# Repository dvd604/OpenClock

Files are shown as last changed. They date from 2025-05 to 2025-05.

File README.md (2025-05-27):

# OpenClock
Raspberry Pi Pico / ESPHome based central heating controller







# Background
I bought a house that had a "dumb" heating controller - a heating clock that switched zones on and off on a schedule. It had three zones, as my house has a hot water, upstairs and downstairs loop.
I replaced it for a Nest Learning Thermostat 3, and was very unimpressed with it - It only had water and one zone, and the app design was terrible. For me (having an oil fired boilder), I wanted to turn the heating on for an hour in the morning to get the house warm, and give me hot water for a shower, and that's about it. Obviously as the name suggests, the Nest Thermostat wanted to get the house to a temperature and hold it there, which didn't work for me.

To fix this, I designed OpenClock - an ESPHome based heating clock built around readily available parts that would integrate into my already mature smart home system, giving me the ability to make the control of this clock as simple or as complex as I wanted. It was also a learning tool for me, being the second time I've designed circuitry for UK mains (240V) applications.

While I wouldn't recommend anyone build this (as I have limited experience with designing mains application devices), and this repo is more for demonstration purposes, I have been using OpenClock for over a year without issue.

# Features

* Designed to screw to a UK single gang backbox
* 3 Heating zones, can be switched on and off independantly
* Runs ESPHome on a RPi Pico, so firmware can be modified

# Heating systems known to work

Only tested in my house - has an oil fired boiler, which is controlled in two ways:

1. The water "zone" sends mains power directly to the water "zone" valve - this valve opens, and a switch inside the valve then powers the boiler.
2. The room "zones" send mains power to a room thermostat - this thermostat has the final say over whether the room "zone" valve opens, which when opened, powers the boiler as above.
 
# The benefit of hindsight

While OpenClock has worked well for over a year, having spent some time with it, I now know how I would do it different - and probably will. If I was doing this centralised control method again, I would buy a Shelly relay - these guys have far more experience than me with designing safe electronics, and their hardware is small enough to fit in a UK backbox. One of their relays probably costs less than the price of the PCBs alone.

However, I've come to strongly dislike my room thermostats - they're loud when switching, difficult to use, and are very feature-light. By this I mean, they turn on and off with temperature in a room.
To fix this, I would hardwire the mains wires where OpenClock is at the moment, so the room thermostats are receiving power all the time, and install something like the Sonoff NSPanel. This would add so many more options into the rooms where the thermostats are mounted.

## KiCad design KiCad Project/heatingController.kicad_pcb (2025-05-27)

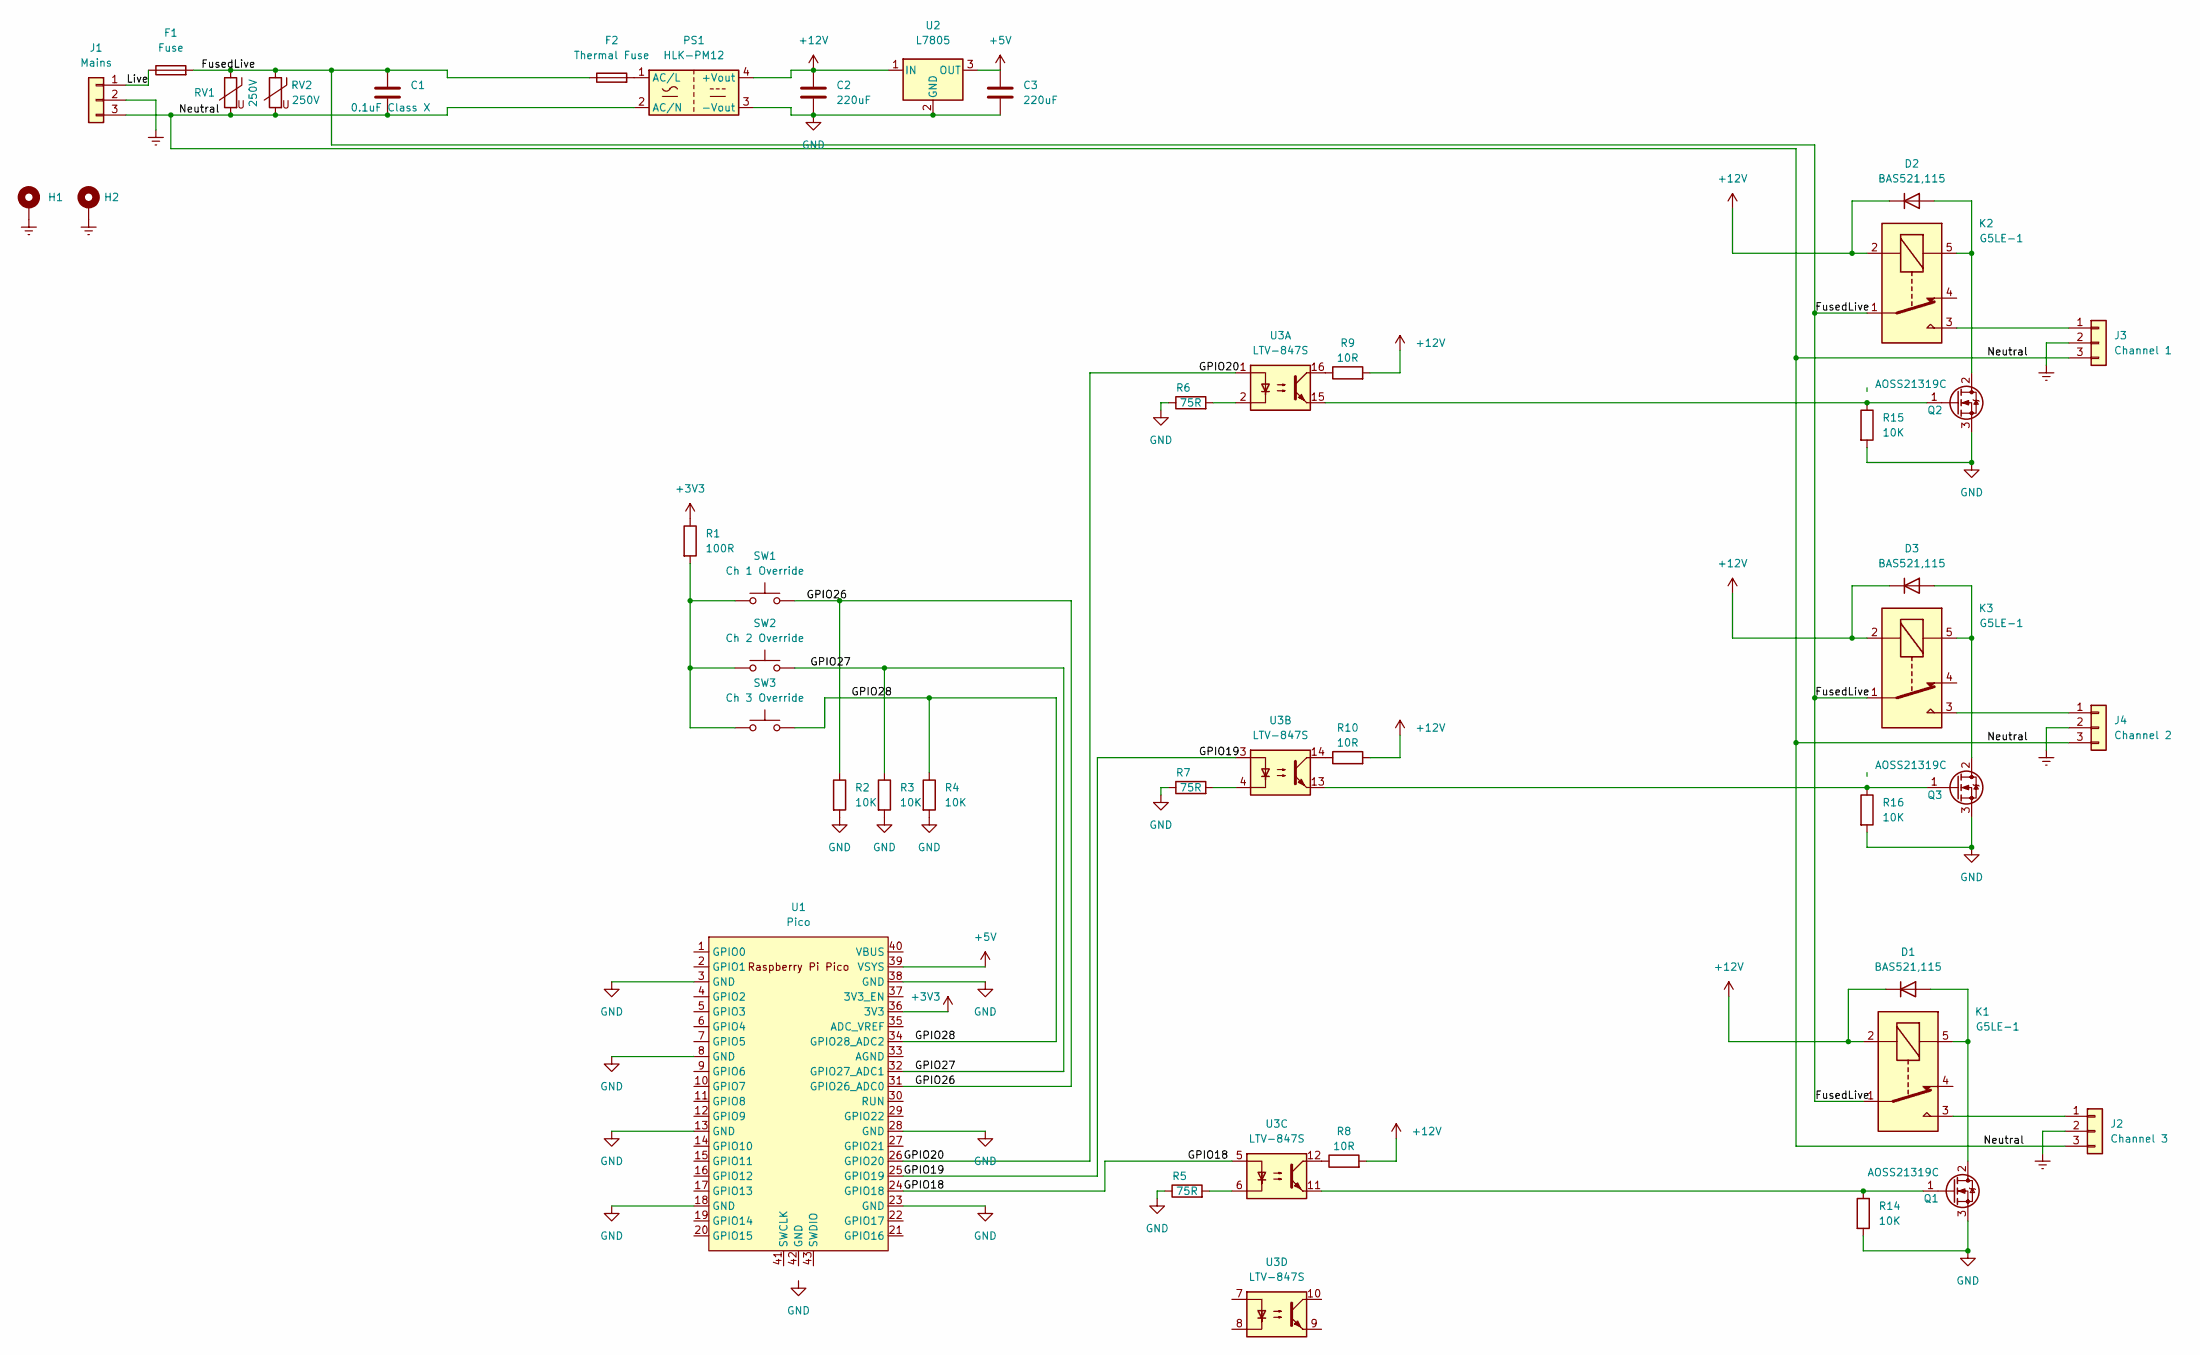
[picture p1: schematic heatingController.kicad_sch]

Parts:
C1: 0.1uF Class X; C_Rect_L18.0mm_W8.0mm_P15.00mm_FKS3_FKP3
C2, C3: 220uF; R_0603_1608Metric_Pad0.98x0.95mm_HandSolder
D1, D2, D3: BAS521,115; D_SOD-523
F1: Fuse; Fuse_BelFuse_0ZRE0100FF_L18.7mm_W5.1mm
F2: Thermal Fuse; PhoenixContact_MSTBVA_2,5_2-G-5,08_1x02_P5.08mm_Vertical
H1, H2: 1; MountingHole_3.2mm_M3_Pad
J1: Mains; PhoenixContact_MSTBVA_2,5_3-G-5,08_1x03_P5.08mm_Vertical
J2: Channel 3; PhoenixContact_MSTBVA_2,5_3-G-5,08_1x03_P5.08mm_Vertical
J3: Channel 1; PhoenixContact_MSTBVA_2,5_3-G-5,08_1x03_P5.08mm_Vertical
J4: Channel 2; PhoenixContact_MSTBVA_2,5_3-G-5,08_1x03_P5.08mm_Vertical
K1, K2, K3: G5LE-1; Relay_SPDT_Omron-G5LE-1
PS1: HLK-PM12; Converter_ACDC_HiLink_HLK-PMxx
Q1, Q2, Q3: AOSS21319C; SOT-23
R1: 100R; R_0603_1608Metric_Pad0.98x0.95mm_HandSolder
R2, R3, R4, R14, R15, R16: 10K; R_0603_1608Metric_Pad0.98x0.95mm_HandSolder
R5, R6, R7: 75R; R_0805_2012Metric_Pad1.20x1.40mm_HandSolder
R8, R9, R10: 10R; R_0805_2012Metric_Pad1.20x1.40mm_HandSolder
RV1, RV2: 250V; RV_Disc_D12mm_W3.9mm_P7.5mm
SW1: Ch 1 Override; PinSocket_1x02_P2.54mm_Vertical
SW2: Ch 2 Override; PinSocket_1x02_P2.54mm_Vertical
SW3: Ch 3 Override; PinSocket_1x02_P2.54mm_Vertical
U1: Pico; RPi_Pico_SMD_TH
U2: L7805; TO-252-3_TabPin2
U3: LTV-847S; SMDIP-16_W9.53mm

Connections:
+3V3: R1.1, U1.36 (3V3)
+5V: C3.1, U1.39 (VSYS), U2.3 (OUT)
+12V: C2.1, D1.1 (K), D2.1 (K), D3.1 (K), K1.2, K2.2, K3.2, PS1.4 (+Vout), R8.2, R9.2, R10.2, U2.1 (IN)
/FusedLive: C1.1, F1.2, F2.1, K1.1, K2.1, K3.1, RV1.1, RV2.1
/GPIO18: U1.24 (GPIO18), U3.5
/GPIO19: U1.25 (GPIO19), U3.3
/GPIO20: U1.26 (GPIO20), U3.1
/GPIO26: R2.1, SW1.2, U1.31 (GPIO26_ADC0)
/GPIO27: R3.1, SW2.2, U1.32 (GPIO27_ADC1)
/GPIO28: R4.1, SW3.2, U1.34 (GPIO28_ADC2)
/Live: F1.1, J1.1
/Neutral: C1.2, J1.3, J2.3, J3.3, J4.3, PS1.2 (AC/N), RV1.2, RV2.2
Earth: H1.1, H2.1, J1.2, J2.2, J3.2, J4.2
GND: C2.2, C3.2, PS1.3 (-Vout), Q1.3 (S), Q2.3 (S), Q3.3 (S), R2.2, R3.2, R4.2, R5.1, R6.1, R7.1, R14.2, R15.2, R16.2, U1.3 (GND), U1.8 (GND), U1.13 (GND), U1.18 (GND), U1.23 (GND), U1.28 (GND), U1.38 (GND), U2.2 (GND)
unnamed: D1.2 (A), K1.5, Q1.2 (D)
unnamed: D2.2 (A), K2.5, Q2.2 (D)
unnamed: D3.2 (A), K3.5, Q3.2 (D)
unnamed: F2.2, PS1.1 (AC/L)
unnamed: J2.1, K1.3
unnamed: J3.1, K2.3
unnamed: J4.1, K3.3
unnamed: Q1.1 (G), R14.1, U3.11
unnamed: Q2.1 (G), R15.1, U3.15
unnamed: Q3.1 (G), R16.1, U3.13
unnamed: R1.2, SW1.1, SW2.1, SW3.1
unnamed: R5.2, U3.6
unnamed: R6.2, U3.2
unnamed: R7.2, U3.4
unnamed: R8.1, U3.12
unnamed: R9.1, U3.16
unnamed: R10.1, U3.14

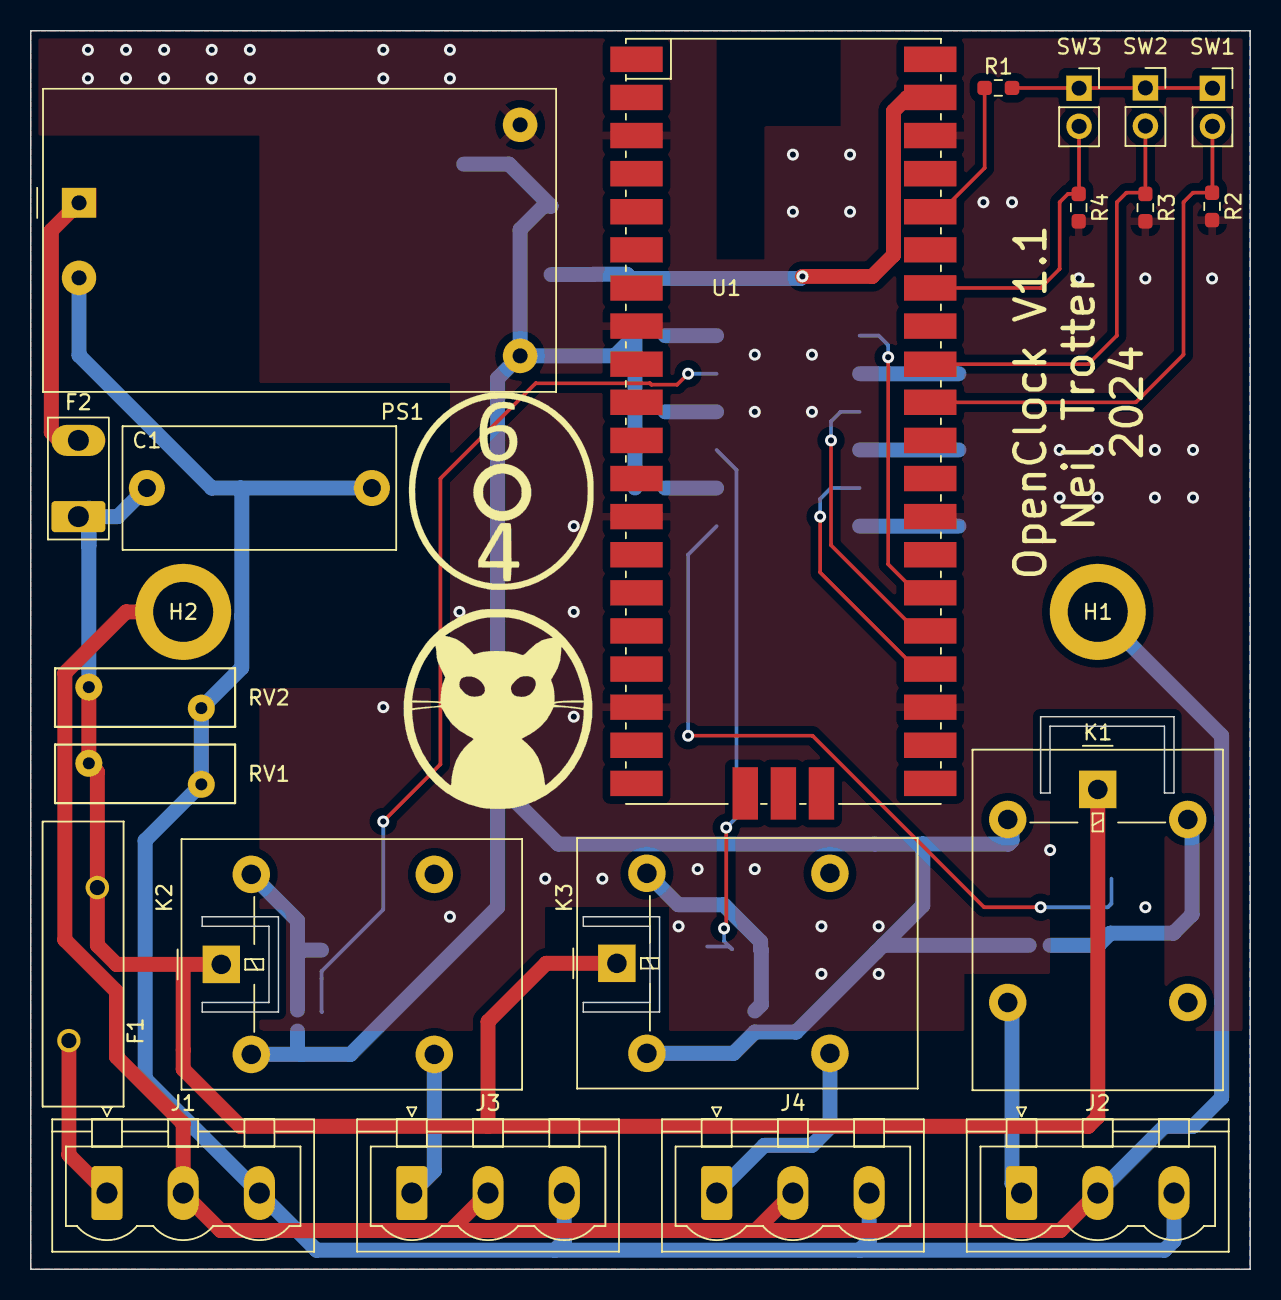
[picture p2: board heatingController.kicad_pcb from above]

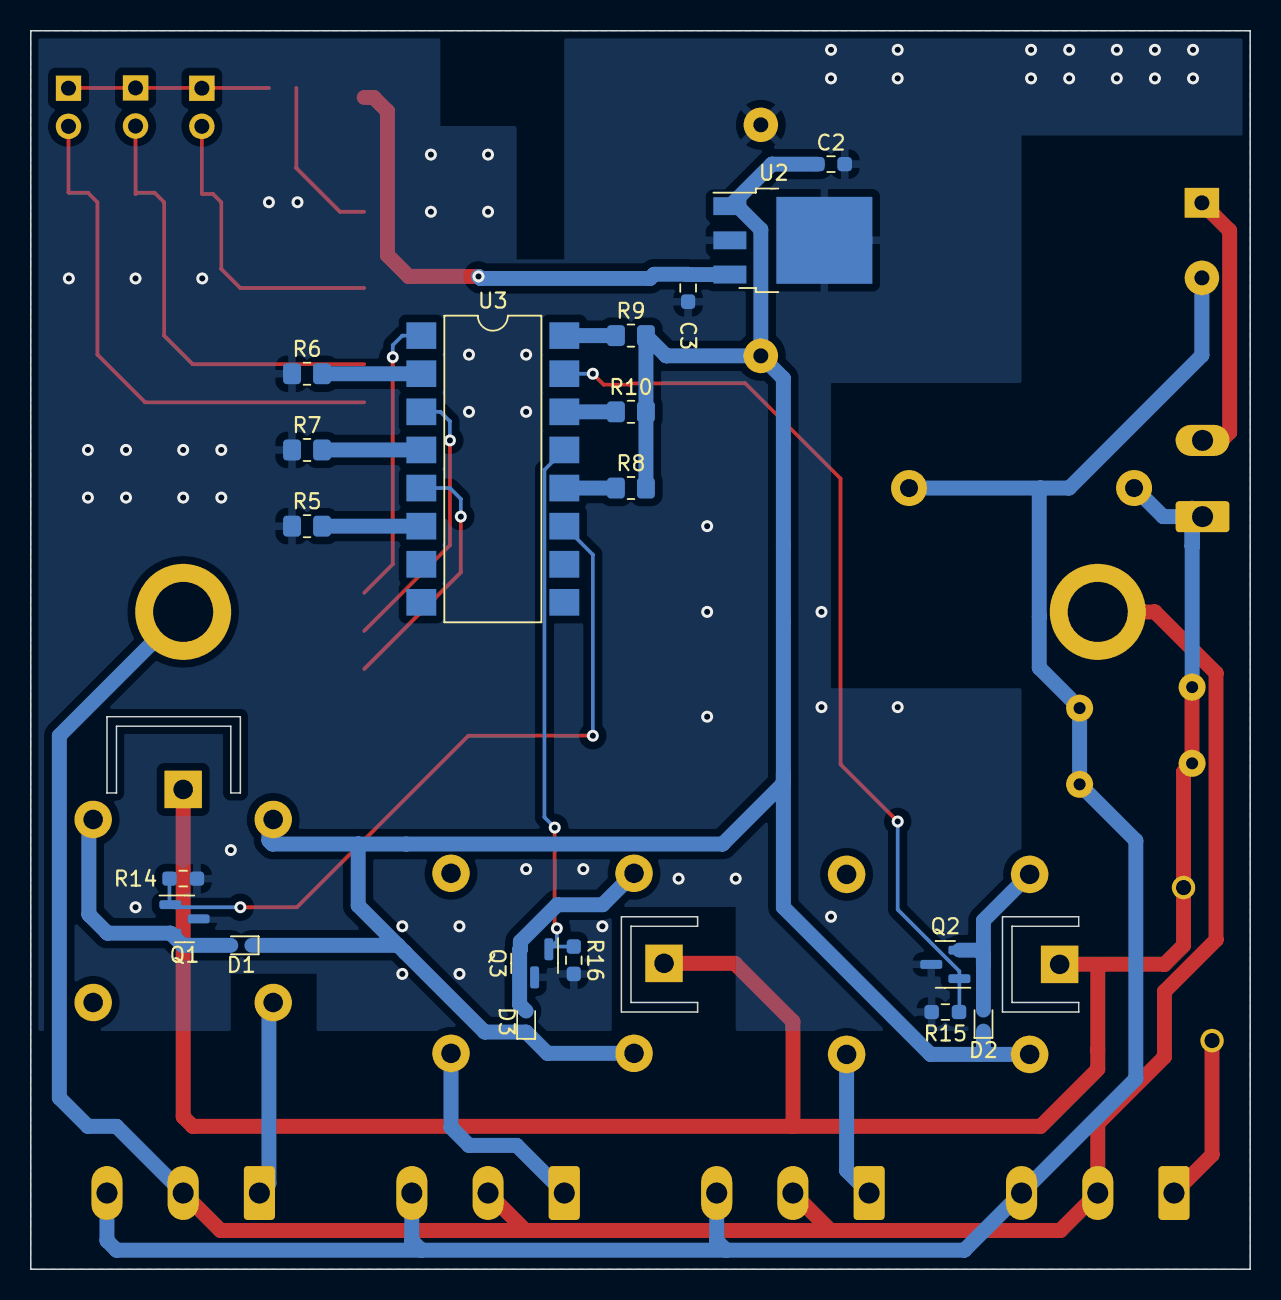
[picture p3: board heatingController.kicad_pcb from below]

Board: 2 copper layers, 81.3 x 82.6 mm, 42 parts (19 on the bottom side), 31 nets.

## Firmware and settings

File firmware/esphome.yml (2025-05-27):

esphome:
  name: openclock
  friendly_name: OpenClock

rp2040:
  board: rpipicow

# Enable logging
logger:
  level: INFO

# Enable Home Assistant API
api:
  encryption:
    key: ""

wifi:
  ssid: !secret wifi_ssid
  password: !secret wifi_password
  
  ap:
    ssid: "Openclock Fallback Hotspot"
    password: ""
    
ota:
  - platform: esphome
    password: ""

globals:
  - id: upstairs_ticks
    type: int
    restore_value: no
    initial_value: "0"
  - id: downstairs_ticks
    type: int
    restore_value: no
    initial_value: "0"
  - id: water_ticks
    type: int
    restore_value: no
    initial_value: "0"

binary_sensor:
  - platform: gpio
    pin: GPIO26
    name: "HW Switch 1"
    id: "hw_switch_1"
    internal: True
    filters:
      - delayed_on: 100ms
    entity_category: "diagnostic"
    on_state: 
      then:
        - lambda: |-
            id(auto_off).turn_on();
            if(id(hw_switch_1).state){

              auto call = id(upstairs_limit).make_call();
              call.number_increment(true);
              call.perform();


            //  id(upstairs_switch).turn_on();
            }

  - platform: gpio
    pin: GPIO27
    name: "HW Switch 2"
    id: "hw_switch_2"
    internal: True
    filters:
      - delayed_on: 100ms
    entity_category: "diagnostic"
    on_state: 
      then:
        - lambda: |-
            id(auto_off).turn_on();
            if(id(hw_switch_2).state){
              
              auto call = id(downstairs_limit).make_call();
              call.number_increment(true);
              call.perform();


             // id(downstairs_switch).turn_on();
            }

  - platform: gpio
    pin: GPIO28
    name: "HW Switch 3"
    id: "hw_switch_3"
    internal: True
    filters:
      - delayed_on: 100ms
    entity_category: "diagnostic"
    on_state: 
      then:
        - lambda: |-
            id(auto_off).turn_on();
            if(id(hw_switch_3).state){

              auto call = id(water_limit).make_call();
              call.number_increment(true);
              call.perform();
              
              //id(water_switch).turn_on();
            }

number:
  - platform: template
    name: "Upstairs duration"
    icon: "mdi:clock-edit"
    id: upstairs_limit
    step: 15
    min_value: 15
    max_value: 120
    optimistic: true
    entity_category: "config"
    unit_of_measurement: "minutes"
  - platform: template
    name: "Downstairs duration"
    icon: "mdi:clock-edit"
    id: downstairs_limit
    step: 15
    min_value: 15
    max_value: 120
    optimistic: true
    entity_category: "config"
    unit_of_measurement: "minutes"
  - platform: template
    name: "Water duration"
    icon: "mdi:clock-edit"
    id: water_limit
    step: 15
    min_value: 15
    max_value: 120
    optimistic: true
    entity_category: "config"
    unit_of_measurement: "minutes"

text_sensor:
  - platform: template
    name: "Upstairs On-Time"
    id: up_ticks_sensor
    entity_category: "diagnostic"
    lambda: 'return {std::to_string(id(upstairs_ticks)/60) + ":" + std::to_string(id(upstairs_ticks)%60)};'
    update_interval: 10s

  - platform: template
    name: "Downstairs On-Time"
    id: down_ticks_sensor
    entity_category: "diagnostic"
    lambda: 'return {std::to_string(id(downstairs_ticks)/60) + ":" + std::to_string(id(downstairs_ticks)%60)};'
    update_interval: 10s

  - platform: template
    name: "Water On-Time"
    id: water_ticks_sensor
    entity_category: "diagnostic"
    lambda: 'return {std::to_string(id(water_ticks)/60) + ":" + std::to_string(id(water_ticks)%60)};'
    update_interval: 10s

switch:
  - platform: restart
    name: "Restart"
    entity_category: "diagnostic"
  - platform: template
    name: "Upstairs heating"
    id: upstairs_switch
    icon: "mdi:radiator"
    restore_mode: ALWAYS_OFF
    optimistic: True
    on_turn_on: 
      output.turn_on: relay_upstairs
    on_turn_off: 
      output.turn_off: relay_upstairs

  - platform: template
    name: "Downstairs heating"
    id: downstairs_switch
    icon: "mdi:radiator"
    restore_mode: ALWAYS_OFF
    optimistic: True
    on_turn_on: 
      - output.turn_on: relay_downstairs
    on_turn_off: 
      - output.turn_off: relay_downstairs

  - platform: template
    name: "Water heater"
    id: water_switch
    icon: "mdi:water"
    optimistic: True
    restore_mode: ALWAYS_OFF
    on_turn_on: 
      - output.turn_on: relay_water
    on_turn_off: 
      - output.turn_off: relay_water

  - platform: template
    name: "Enable Auto-Off"
    id: auto_off
    optimistic: True
    device_class: "switch"
    entity_category: "config"
    restore_mode: ALWAYS_ON
    on_turn_on: 
      then:
        - lambda: id(timer_tick).execute();
    on_turn_off: 
      then:
        - lambda: |-
            id(timer_tick).stop();
            id(water_ticks) = 0;
            id(upstairs_ticks) = 0;
            id(downstairs_ticks) = 0;

sensor:
  - platform: adc
    pin: TEMPERATURE
    name: "Core Temperature"
    entity_category: "diagnostic"
    unit_of_measurement: "°C"
    filters:
      - lambda: return 27 - (x - 0.706f) / 0.001721f;
  - platform: adc
    pin: VCC
    name: "VCC Voltage"
    unit_of_measurement: "V"
    entity_category: "diagnostic"

output:
  - platform: gpio
    id: relay_upstairs
    pin: GPIO18
    inverted: true
  - platform: gpio
    id: relay_downstairs
    pin: GPIO19
    inverted: true
  - platform: gpio
    id: relay_water
    pin: GPIO20
    inverted: true

script:
  - id: timer_tick
    mode: queued
    then:
      - delay: 1s
      - lambda: |-
            //if(!id(auto_off).state) return;

            if(id(upstairs_switch).state) {
              id(upstairs_ticks) ++;
            } else {
              id(upstairs_ticks) = 0;
            }

            if(id(downstairs_switch).state) {
              id(downstairs_ticks) ++;
            } else {
              id(downstairs_ticks) = 0;
            }

            if(id(water_switch).state) {
              id(water_ticks) ++;
            } else {
              id(water_ticks) = 0;
            }

            if(id(water_ticks) >= id(water_limit).state * 60){
              id(relay_water).turn_off();
              id(water_switch).turn_off();
              id(water_ticks) = 0;
            }

            if(id(upstairs_ticks) >= id(upstairs_limit).state * 60){
              id(relay_upstairs).turn_off();
              id(upstairs_switch).turn_off();
              id(upstairs_ticks) = 0;
            }

            if(id(downstairs_ticks) >= id(downstairs_limit).state * 60){
              id(relay_downstairs).turn_off();
              id(downstairs_switch).turn_off();
              id(downstairs_ticks) = 0;
            } 

            id(timer_tick).execute();
